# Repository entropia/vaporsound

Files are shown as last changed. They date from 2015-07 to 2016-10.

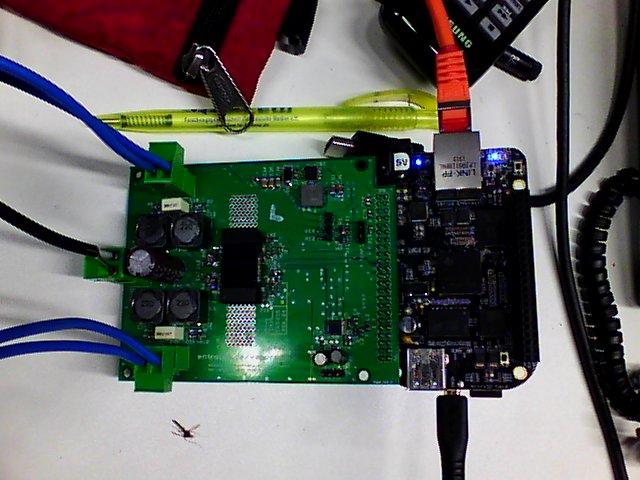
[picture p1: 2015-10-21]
docs/flir/front1.jpg

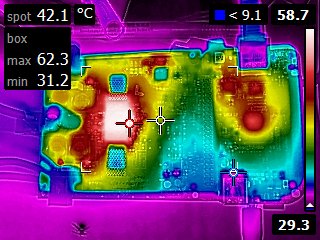
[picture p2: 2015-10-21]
docs/flir/front1_ir.jpg

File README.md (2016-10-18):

# vaporsound

Our custom audio amplifier for the hackerspace

## hardware

The vaporsound board can drive two speakers with up to 50W each and has an analog stereo input.
It is connected to a beaglebone black which provides an ethernet port.
The vaporsound board needs a 24V power supply and provides 5V to the beaglebone black.

The hardware is designed in Eagle.

## mechanical

The vaporsound case is designed in Rhino3D and can be lasercut from 4mm wood.

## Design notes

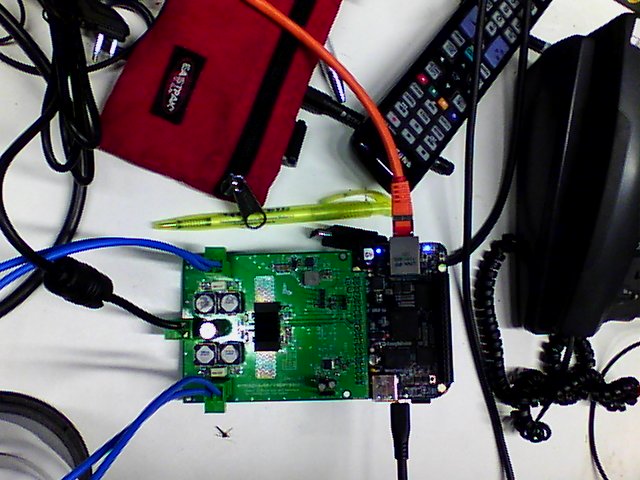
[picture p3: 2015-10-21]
docs/flir/front2.jpg

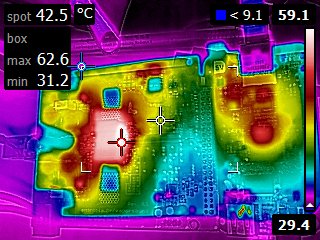
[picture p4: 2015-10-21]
docs/flir/front3_ir.jpg

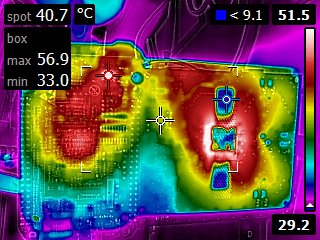
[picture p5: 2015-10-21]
docs/flir/back2_ir.jpg

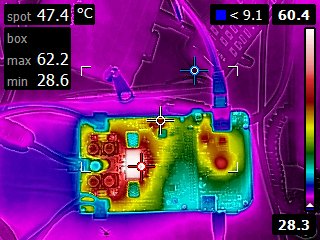
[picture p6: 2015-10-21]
docs/flir/front2_ir.jpg

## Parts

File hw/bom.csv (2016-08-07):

 | Part | Value | Device | Package | Description | MF | MPN | OC_FARNELL | OC_NEWARK | PROD_ID
X | R1 | 0R | R-EU_R0603 | R0603 | RESISTOR, European symbol
X | R2 | 0R | R-EU_R0603 | R0603 | RESISTOR, European symbol
X | R16 | 0R | R-EU_R0603 | R0603 | RESISTOR, European symbol
X | C41 | 1000u | CPOL-EUE5-10.5 | E5-10,5 | POLARIZED CAPACITOR, European symbol
vorhanden | C1 | 100n | C-EUC0603 | C0603 | CAPACITOR, European symbol
vorhanden | C3 | 100n | C-EUC0603 | C0603 | CAPACITOR, European symbol
vorhanden | C5 | 100n | C-EUC0603 | C0603 | CAPACITOR, European symbol
vorhanden | C11 | 100n | C-EUC0603 | C0603 | CAPACITOR, European symbol
vorhanden | C12 | 100n | C-EUC0603 | C0603 | CAPACITOR, European symbol
vorhanden | C13 | 100n | C-EUC0603 | C0603 | CAPACITOR, European symbol
vorhanden | C18 | 100n | C-EUC0603 | C0603 | CAPACITOR, European symbol
vorhanden | C19 | 100n | C-EUC0603 | C0603 | CAPACITOR, European symbol
vorhanden | C20 | 100n | C-EUC0603 | C0603 | CAPACITOR, European symbol
vorhanden | C21 | 100n | C-EUC0603 | C0603 | CAPACITOR, European symbol
vorhanden | C22 | 100n | C-EUC0603 | C0603 | CAPACITOR, European symbol
vorhanden | C23 | 100n | C-EUC0603 | C0603 | CAPACITOR, European symbol
vorhanden | C24 | 100n | C-EUC0603 | C0603 | CAPACITOR, European symbol
vorhanden | C25 | 100n | C-EUC0603 | C0603 | CAPACITOR, European symbol
vorhanden | C39 | 100n | C-EUC0603 | C0603 | CAPACITOR, European symbol
vorhanden | C40 | 100n | C-EUC0603 | C0603 | CAPACITOR, European symbol
vorhanden | C42 | 100n | C-EUC0603 | C0603 | CAPACITOR, European symbol
vorhanden | C43 | 100n | C-EUC0603 | C0603 | CAPACITOR, European symbol
vorhanden | R15 | 10k | R-EU_R0603 | R0603 | RESISTOR, European symbol
vorhanden | R1 | 10k | R-EU_R0805 | R0805 | RESISTOR, European symbol
vorhanden | R2 | 10k | R-EU_R0805 | R0805 | RESISTOR, European symbol
vorhanden | R3 | 10k | R-EU_R0805 | R0805 | RESISTOR, European symbol
vorhanden | R4 | 10k | R-EU_R0805 | R0805 | RESISTOR, European symbol
vorhanden | R5 | 10k | R-EU_R0805 | R0805 | RESISTOR, European symbol
X | C30 | 10n | C-EUC0603 | C0603 | CAPACITOR, European symbol
X | C2 | 10u | C-EUC0805 | C0805 | CAPACITOR, European symbol
X | C4 | 10u | C-EUC0805 | C0805 | CAPACITOR, European symbol
X | C6 | 10u | C-EUC0805 | C0805 | CAPACITOR, European symbol
X | C34 | 10u | C-EUC1206 | C1206 | CAPACITOR, European symbol
X | C35 | 10u | C-EUC1206 | C1206 | CAPACITOR, European symbol
X | C36 | 10u | C-EUC1206 | C1206 | CAPACITOR, European symbol
X | C44 | 1n | C-EUC0603 | C0603 | CAPACITOR, European symbol
X | C7 | 1u | CPOL-EUE2-5 | E2-5 | POLARIZED CAPACITOR, European symbol
X | C8 | 1u | CPOL-EUE2-5 | E2-5 | POLARIZED CAPACITOR, European symbol
X | C33 | 1u | C-EUC0805 | C0805 | CAPACITOR, European symbol
X | C37 | 1u | C-EUC1206 | C1206 | CAPACITOR, European symbol
X | C38 | 1u | C-EUC1206 | C1206 | CAPACITOR, European symbol
X | L2 | 1uH | R-EU_R0805 | R0805 | RESISTOR, European symbol
X | L7 | 1uH | R-EU_R0805 | R0805 | RESISTOR, European symbol
X | R5 | 20R | R-EU_R1206 | R1206 | RESISTOR, European symbol
X | R6 | 20R | R-EU_R1206 | R1206 | RESISTOR, European symbol
X | C45 | 22u | C-EUC1206 | C1206 | CAPACITOR, European symbol
X | L1 | 22u | L-EUSRR1210 | SRR1210 | INDUCTOR, European symbol
X | L3 | 22u | L-EUSRR1210 | SRR1210 | INDUCTOR, European symbol
X | L4 | 22u | L-EUSRR1210 | SRR1210 | INDUCTOR, European symbol
X | L5 | 22u | L-EUSRR1210 | SRR1210 | INDUCTOR, European symbol
X | L6 | 22u | L-EUIHLP-3232DZ-11 | IHLP-3232DZ-11 | INDUCTOR, European symbol
X | R4 | 2k2 | R-EU_R0603 | R0603 | RESISTOR, European symbol
X | R3 | 2R2 | R-EU_R0603 | R0603 | RESISTOR, European symbol
X | C16 | 330p | C-EUC0603 | C0603 | CAPACITOR, European symbol
X | C17 | 330p | C-EUC0603 | C0603 | CAPACITOR, European symbol
X | R6 | 330R | R-EU_R0805 | R0805 | RESISTOR, European symbol
X | C26 | 470n | C-EU050-045X075 | C050-045X075 | CAPACITOR, European symbol
X | C27 | 470n | C-EU050-045X075 | C050-045X075 | CAPACITOR, European symbol
X | C31 | 47u | C-EUC1206 | C1206 | CAPACITOR, European symbol
X | C32 | 47u | C-EUC1206 | C1206 | CAPACITOR, European symbol
X | R11 | 4k7 | R-EU_R0603 | R0603 | RESISTOR, European symbol
X | R12 | 4k7 | R-EU_R0603 | R0603 | RESISTOR, European symbol
X | R13 | 4k7 | R-EU_R0603 | R0603 | RESISTOR, European symbol
X | R14 | 4k7 | R-EU_R0603 | R0603 | RESISTOR, European symbol
X | R19 | 4k7 | R-EU_R0603 | R0603 | RESISTOR, European symbol
X | C14 | 4n7 | C-EUC0603 | C0603 | CAPACITOR, European symbol
X | C28 | 4u7 | C-EUC0805 | C0805 | CAPACITOR, European symbol
X | C29 | 4u7 | C-EUC0805 | C0805 | CAPACITOR, European symbol
X | C15 | 680p | C-EUC0603 | C0603 | CAPACITOR, European symbol
X | R7 | 6R2 | R-EU_R1206 | R1206 | RESISTOR, European symbol
X | R8 | 6R2 | R-EU_R1206 | R1206 | RESISTOR, European symbol
X | R9 | 6R2 | R-EU_R1206 | R1206 | RESISTOR, European symbol
X | R10 | 6R2 | R-EU_R1206 | R1206 | RESISTOR, European symbol
X | D1 | B340A-13-F | DIODESMA | SMADIODE | Diode
X | T1 | BC847C | BC847A-NPN-SOT23-BEC | SOT23-BEC | NPN Transistror
X | Q1 | BSS138 | MOSFET-NCHANNELBSS138 | SOT23-3 | Common NMOSFET Parts |  |  |  |  | TRANS-00830
X | Q2 | BSS138 | MOSFET-NCHANNELBSS138 | SOT23-3 | Common NMOSFET Parts |  |  |  |  | TRANS-00830
 | C9 | DNP | C-EUC0603 | C0603 | CAPACITOR, European symbol
 | C10 | DNP | C-EUC0603 | C0603 | CAPACITOR, European symbol
 | R17 | DNP | R-EU_R0603 | R0603 | RESISTOR, European symbol
 | R18 | DNP | R-EU_R0603 | R0603 | RESISTOR, European symbol
X | SW1 | EC12E_SW | EC12E_SW | ALPS_EC12E_SW | ALPS rotary Encoder EC12E series with switch |  | EC12E2424407 | 1520813 | 74M1068
X | U$2 | LM22676 | LM2267_123 | DDA0008B | LM2267x
X | P9 | MA23-2 | MA23-2 | MA23-2
X | P8 | MA23-2 | MA23-2 | MA23-2
X | PWR | MSTBV2 | MSTBV2 | MSTBV2 | PHOENIX |  | MSTBV 2,5/2-GF-5.08 | 1792792 | 69R9845
X | SPKR1 | MSTBV2 | MSTBV2 | MSTBV2 | PHOENIX |  | MSTBV 2,5/2-GF-5.08 | 1792792 | 69R9845
X | SPKR2 | MSTBV2 | MSTBV2 | MSTBV2 | PHOENIX |  | MSTBV 2,5/2-GF-5.08 | 1792792 | 69R9845
X | U$3 | PCM1808 | PCM1808 | TSSOP14
X | U$1 | STA350BW | STA350BW | POWERSSO-36
X | DISP |  | MA04-1 | MA04-1 | PIN HEADER |  |  | unknown | unknown
X | IN |  | MA03-1 | MA03-1 | PIN HEADER |  |  | unknown | unknown
X | TEMP |  | MA03-1 | MA03-1 | PIN HEADER |  |  | unknown | unknown
X | ENCODER |  | PINHD-1X4/90 | 1X04/90 | PIN HEADER
X | PWN_BTN_LED |  | PINHD-1X4/90 | 1X04/90 | PIN HEADER
X | PWR_CON |  | PINHD-1X2/90 | 1X02/90 | PIN HEADER
X | JP1 |  | PINHD-1X4/90 | 1X04/90 | PIN HEADER
X | LED1 |  | LED3MM | LED3MM | LED
X | S1 |  | 40-XX | B3F-40XX | OMRON SWITCH | OMRON COMPONENTS USA | B3F-4000 | 176434 | 36K3105
X | JP1 |  | PINHD-1X4/90 | 1X04/90 | PIN HEADER

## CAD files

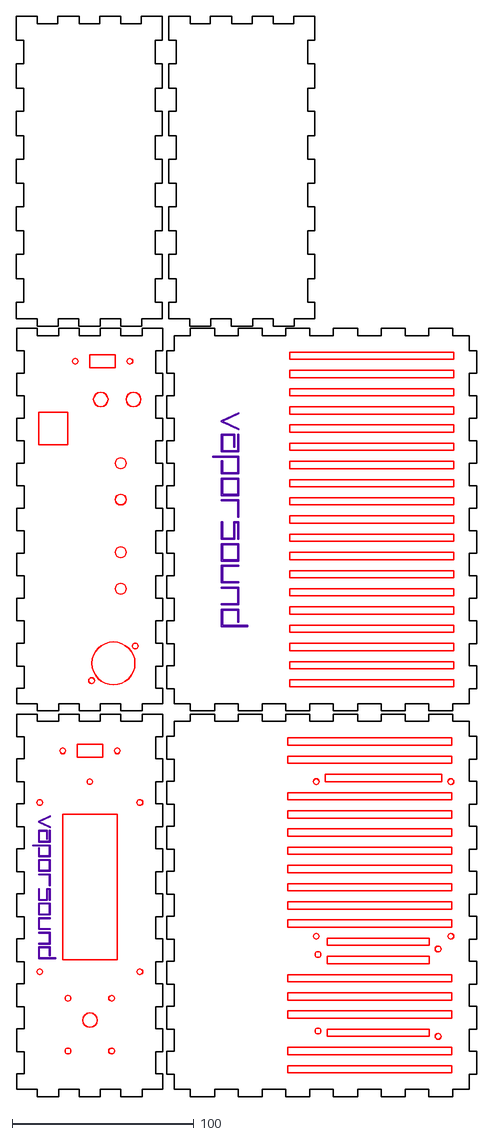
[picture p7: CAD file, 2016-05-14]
mechanical/vaporsound_case.dxf
252.8 x 593.6

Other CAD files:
mechanical/vaporsound_case.3dm

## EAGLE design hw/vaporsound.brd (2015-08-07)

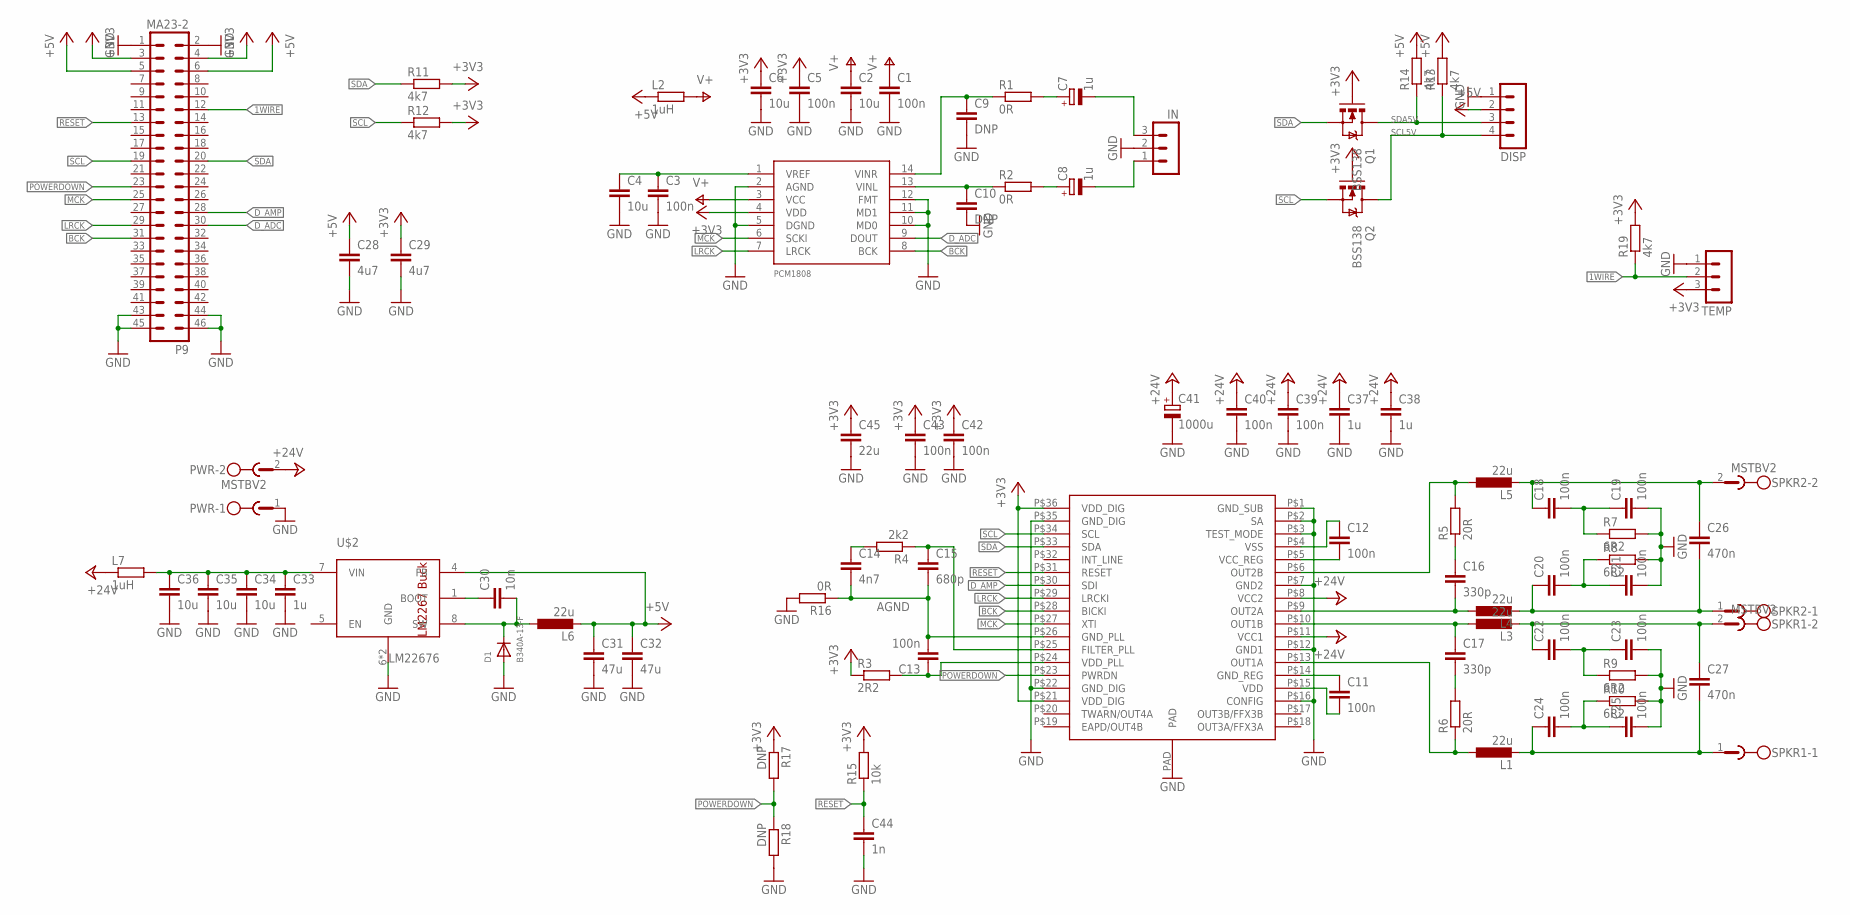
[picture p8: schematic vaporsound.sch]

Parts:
C1, C3, C5, C11, C12, C13, C18, C19, C20, C21, C22, C23, C24, C25, C39, C40, C42, C43: 100n; C0603
C2, C4, C6: 10u; C0805
C7, C8: 1u; E2-5
C9, C10: DNP; C0603
C14: 4n7; C0603
C15: 680p; C0603
C16, C17: 330p; C0603
C26, C27: 470n; C050-045X075
C28, C29: 4u7; C0805
C30: 10n; C0603
C31, C32: 47u; C1206
C33: 1u; C0805
C34, C35, C36: 10u; C1206
C37, C38: 1u; C1206
C41: 1000u; E5-10,5
C44: 1n; C0603
C45: 22u; C1206
D1: B340A-13-F; SMADIODE
DISP: MA04-1
IN: MA03-1
L1, L3, L4, L5: 22u; SRR1210
L2, L7: 1uH; R0805
L6: 22u; IHLP-3232DZ-11
P9: MA23-2
PWR: MSTBV2
Q1, Q2: BSS138; SOT23-3
R1, R2, R16: 0R; R0603
R3: 2R2; R0603
R4: 2k2; R0603
R5, R6: 20R; R1206
R7, R8, R9, R10: 6R2; R1206
R11, R12, R13, R14, R19: 4k7; R0603
R15: 10k; R0603
R17, R18: DNP; R0603
SPKR1, SPKR2: MSTBV2
TEMP: MA03-1
U$1: STA350BW; POWERSSO-36
U$2: LM22676; DDA0008B
U$3: PCM1808; TSSOP14

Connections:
1WIRE: P9.12, R19.1, TEMP.2
24V_DIGITAL: C33.1, C34.1, C35.1, C36.1, L7.2, U$2.7 (VIN)
+3V3: C5.1, C6.1, C29.1, C42.1, C43.1, C45.1, P9.3, P9.4, Q1.1 (G), Q2.1 (G), R3.1, R11.2, R12.2, R15.2, R17.1, R19.2, TEMP.3, U$1.P$21 (VDD_DIG), U$1.P$36 (VDD_DIG), U$3.4 (VDD)
+5V: C28.1, C31.1, C32.1, DISP.2, L2.1, L6.P$2 (2), P9.5, P9.6, R13.2, R14.2, U$2.4 (FB)
+24V: C37.1, C38.1, C39.1, C40.1, C41.+, L7.1, PWR.2, U$1.P$8 (VCC2), U$1.P$11 (VCC1)
ADC_VREF: C3.1, C4.1, U$3.1 (VREF)
AGND: C13.2, C14.2, C15.2, R16.1, U$1.P$26 (GND_PLL)
BCK: P9.31, U$1.P$28 (BICKI), U$3.8 (BCK)
BOOST: C30.1, U$2.1 (BOOT)
C_LEFT: C8.+, R2.2
C_RIGHT: C7.+, R1.2
D_ADC: P9.30, U$3.9 (DOUT)
D_AMP: P9.28, U$1.P$30 (SDI)
FILTER_PLL: C15.1, R4.1, U$1.P$25 (FILTER_PLL)
GND: C1.2, C2.2, C3.2, C4.2, C5.2, C6.2, C9.2, C10.2, C19.2, C21.2, C23.2, C25.2, C28.2, C29.2, C31.2, C32.2, C33.2, C34.2, C35.2, C36.2, C37.2, C38.2, C39.2, C40.2, C41.-, C42.2, C43.2, C44.2, C45.2, D1.A, DISP.1, IN.2, P9.1, P9.2, P9.43, P9.44, P9.45, P9.46, PWR.1, R7.2, R8.2, R9.2, R10.2, R16.2, R18.2, TEMP.1, U$1.P$1 (GND_SUB), U$1.P$2 (SA), U$1.P$3 (TEST_MODE), U$1.P$7 (GND2), U$1.P$12 (GND1), U$1.P$16 (CONFIG), U$1.P$22 (GND_DIG), U$1.P$35 (GND_DIG), U$1.PAD, U$2.6 (GND), U$2.EPAD (GND), U$3.2 (AGND), U$3.5 (DGND), U$3.10 (MD0), U$3.11 (MD1), U$3.12 (FMT)
GND_REG: C11.1, U$1.P$14 (GND_REG)
LEFT_INPUT: C8.-, IN.1
LRCK: P9.29, U$1.P$29 (LRCKI), U$3.7 (LRCK)
MCK: P9.25, U$1.P$27 (XTI), U$3.6 (SCKI)
unnamed: C17.2, R6.2
unnamed: C14.1, R4.2
unnamed: C16.1, R5.1
unnamed: C18.2, C19.1, R7.1
unnamed: C20.2, C21.1, R8.1
unnamed: C24.2, C25.1, R10.1
unnamed: C22.2, C23.1, R9.1
OUT1A: L1.P$1 (1), R6.1, U$1.P$13 (OUT1A)
OUT1B: C17.1, L3.P$1 (1), U$1.P$10 (OUT1B)
OUT2A: C16.2, L4.P$1 (1), U$1.P$9 (OUT2A)
OUT2B: L5.P$1 (1), R5.2, U$1.P$6 (OUT2B)
POWERDOWN: P9.23, R17.2, R18.1, U$1.P$23 (PWRDN)
RESET: C44.1, P9.13, R15.1, U$1.P$31 (RESET)
RIGHT_INPUT: C7.-, IN.3
SCL: P9.19, Q2.2 (S), R12.1, U$1.P$34 (SCL)
SCL5V: DISP.4, Q2.3 (D), R13.1
SDA: P9.20, Q1.2 (S), R11.1, U$1.P$33 (SDA)
SDA5V: DISP.3, Q1.3 (D), R14.1
SPKR1A: C24.1, C27.2, L1.P$2 (2), SPKR1.1
SPKR1B: C22.1, C27.1, L3.P$2 (2), SPKR1.2
SPKR2A: C20.1, C26.2, L4.P$2 (2), SPKR2.1
SPKR2B: C18.1, C26.1, L5.P$2 (2), SPKR2.2
SW: C30.2, D1.C, L6.P$1 (1), U$2.8 (SW)
V+: C1.1, C2.1, L2.2, U$3.3 (VCC)
VCC_REG: C12.2, U$1.P$5 (VCC_REG)
VDD: C11.2, U$1.P$15 (VDD)
VDD_PLL: C13.1, R3.2, U$1.P$24 (VDD_PLL)
VIN_L: C10.1, R2.1, U$3.13 (VINL)
VIN_R: C9.1, R1.1, U$3.14 (VINR)
VSS: C12.1, U$1.P$4 (VSS)

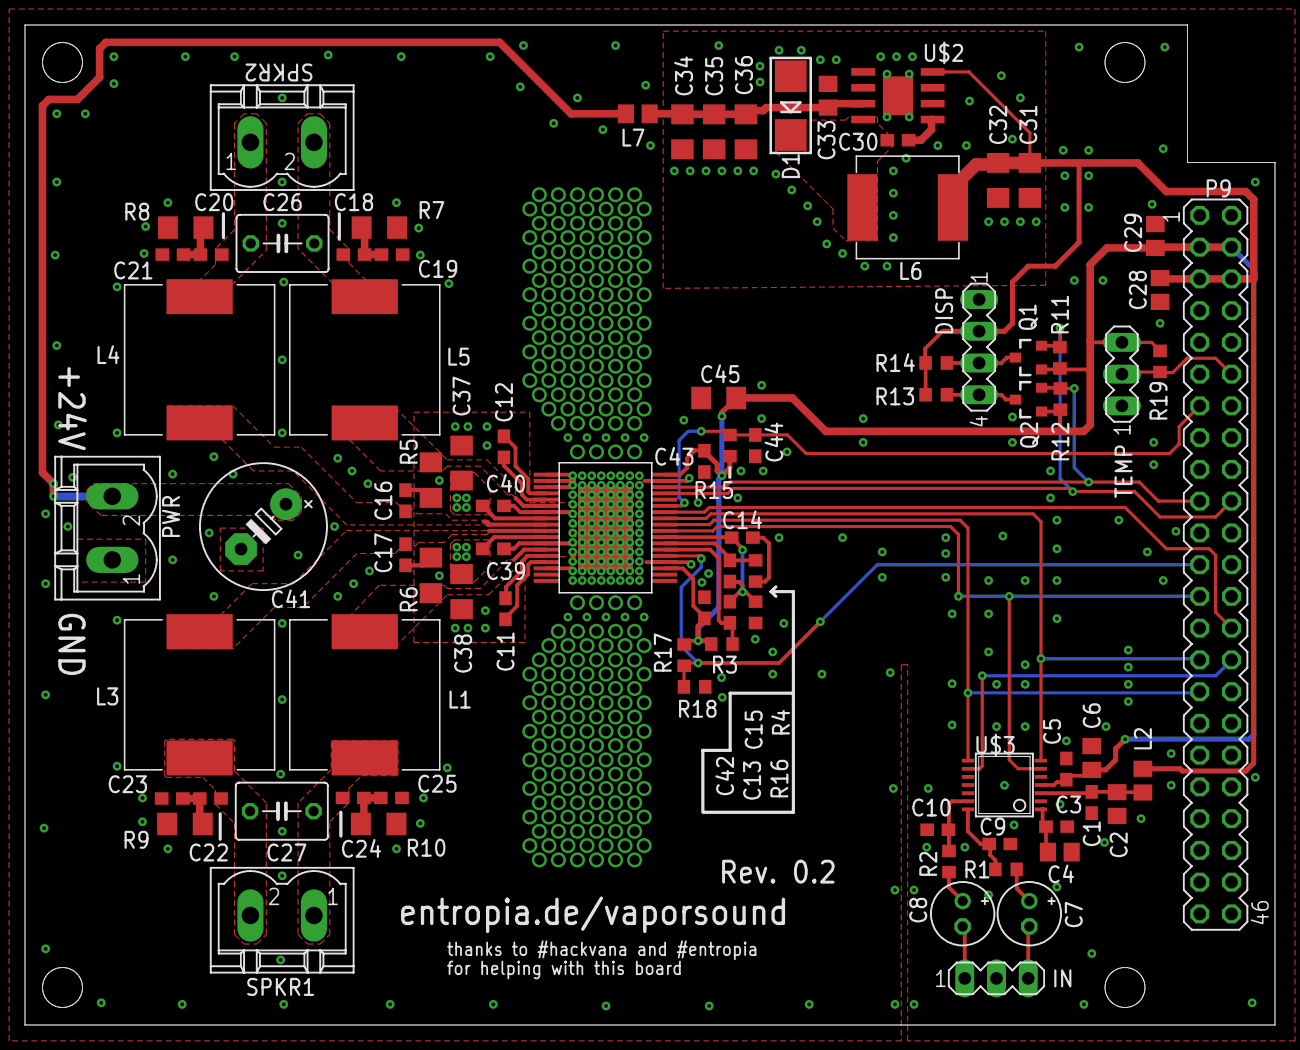
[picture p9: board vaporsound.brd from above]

Board: 2 copper layers, 100.0 x 80.0 mm, 84 parts (0 on the bottom side), 49 nets.

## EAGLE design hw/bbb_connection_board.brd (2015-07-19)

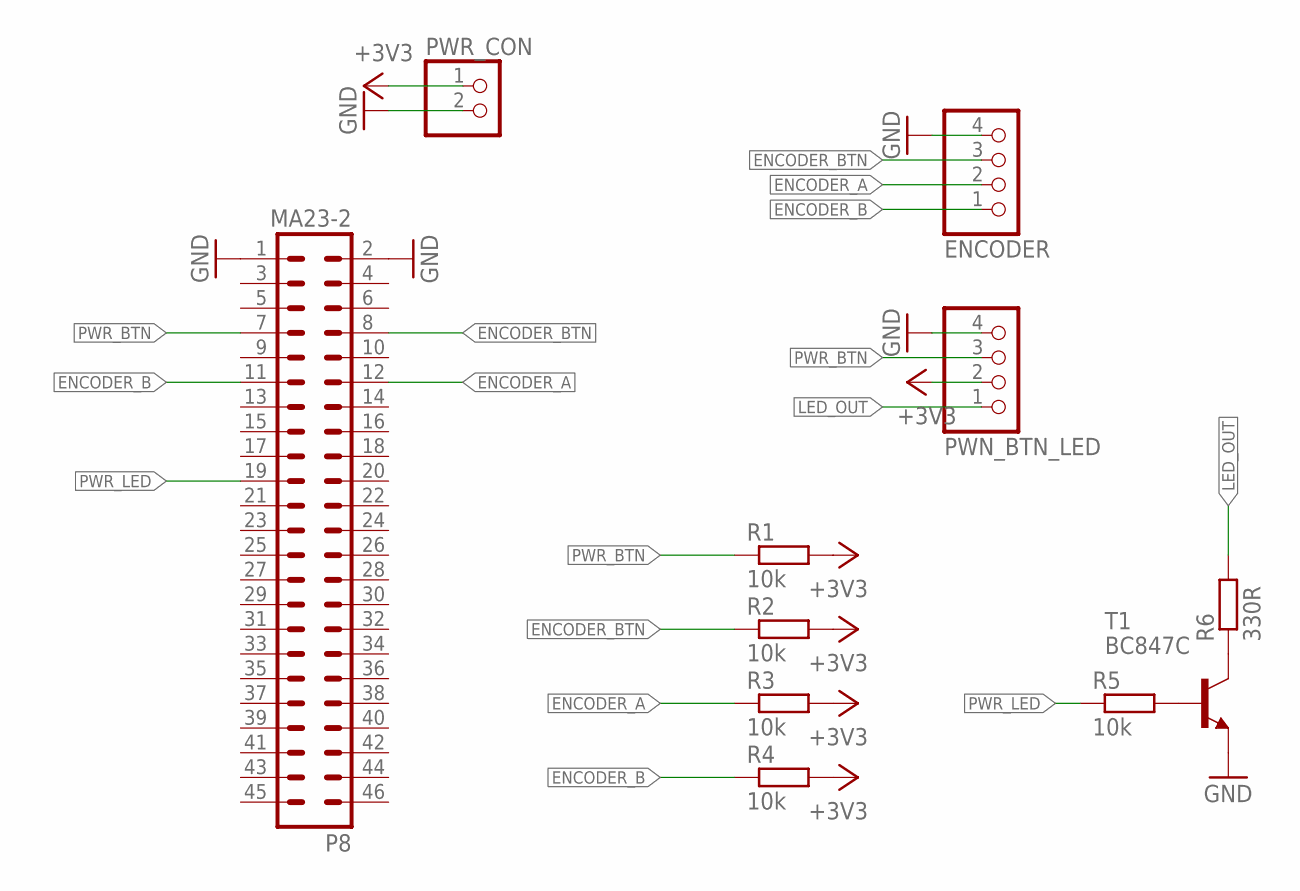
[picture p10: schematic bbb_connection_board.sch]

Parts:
ENCODER: PINHD-1X4/90; 1X04/90
P8: MA23-2
PWN_BTN_LED: PINHD-1X4/90; 1X04/90
PWR_CON: PINHD-1X2/90; 1X02/90
R1, R2, R3, R4, R5: 10k; R0805
R6: 330R; R0805
T1: BC847C; SOT23-BEC

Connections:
+3V3: PWN_BTN_LED.2, PWR_CON.1, R1.2, R2.2, R3.2, R4.2
ENCODER_A: ENCODER.2, P8.12, R3.1
ENCODER_B: ENCODER.1, P8.11, R4.1
ENCODER_BTN: ENCODER.3, P8.8, R2.1
GND: ENCODER.4, P8.1, P8.2, PWN_BTN_LED.4, PWR_CON.2, T1.E
LED_OUT: PWN_BTN_LED.1, R6.2
unnamed: R5.2, T1.B
unnamed: R6.1, T1.C
PWR_BTN: P8.7, PWN_BTN_LED.3, R1.1
PWR_LED: P8.19, R5.1

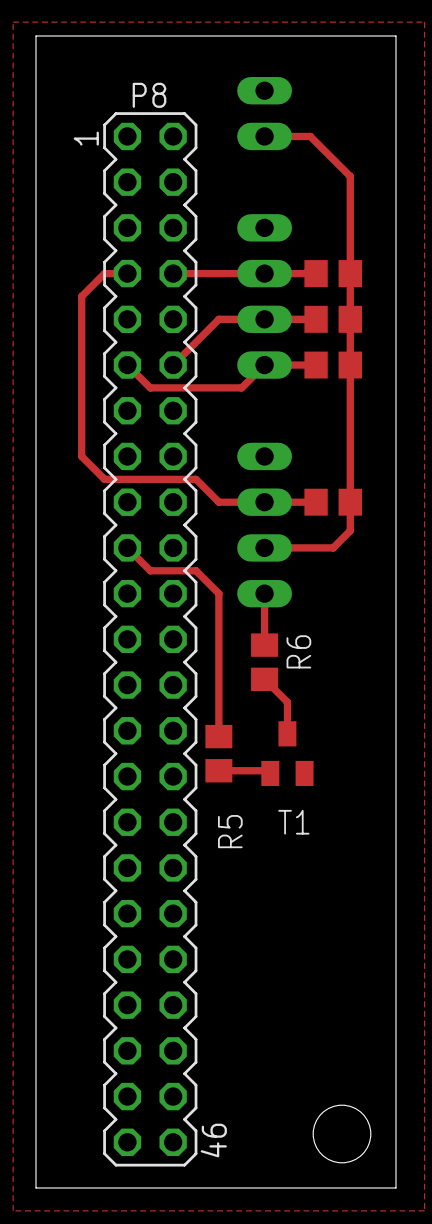
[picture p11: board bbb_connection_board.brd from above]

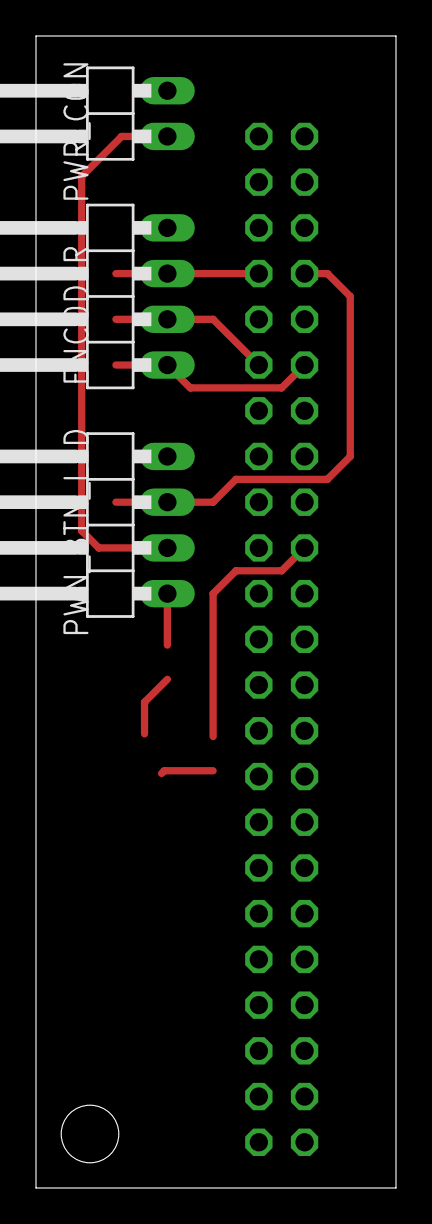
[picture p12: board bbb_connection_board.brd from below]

Board: 2 copper layers, 20.0 x 64.0 mm, 11 parts (3 on the bottom side), 10 nets.

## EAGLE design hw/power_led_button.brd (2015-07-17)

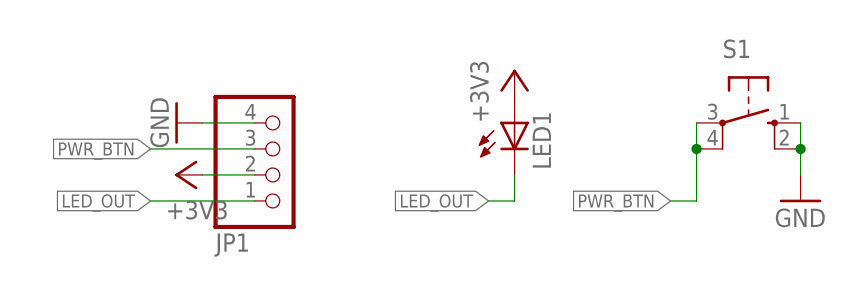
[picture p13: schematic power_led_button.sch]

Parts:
JP1: PINHD-1X4/90; 1X04/90
LED1: LED3MM
S1: 40-XX; B3F-40XX

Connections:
+3V3: JP1.2, LED1.A
GND: JP1.4, S1.1 (S), S1.2 (S1)
LED_OUT: JP1.1, LED1.K (C)
PWR_BTN: JP1.3, S1.3, S1.4 (P1)

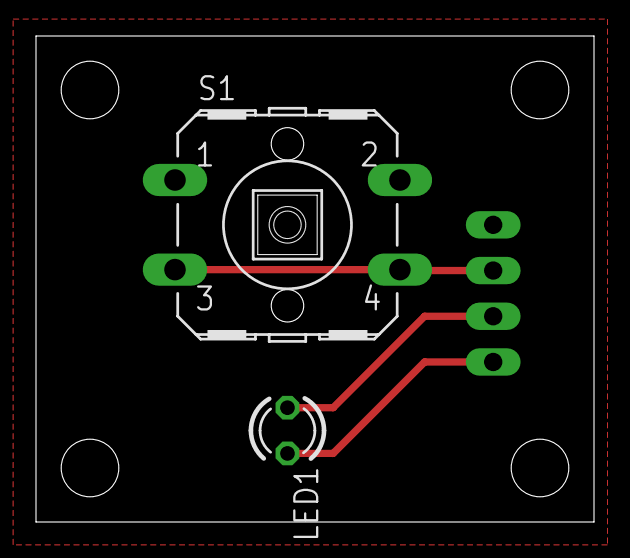
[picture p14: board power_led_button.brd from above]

Board: 2 copper layers, 31.0 x 27.0 mm, 3 parts (1 on the bottom side), 4 nets.

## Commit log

2015-06-24 initial schematic draft
    [vaporsound.brd, vaporsound.sch]
2015-06-29 schematics done-ish
    [vaporsound.brd, vaporsound.sch]
2015-07-06 layout voltage regulator and add some capacitors
    [vaporsound.brd, vaporsound.sch]
2015-07-06 add gerbers of eval board
    [NCDrill.drl]
2015-07-06 modify footprint so it can be produced without additional fee
    minimal distance between traces should be 6mil
2015-07-06 begin layout of 24v side of sta350
    [vaporsound.brd, vaporsound.sch]
2015-07-06 output stage almost routed
    [vaporsound.brd, vaporsound.sch]
2015-07-07 begin component placement at input side of sta350
    [vaporsound.brd, vaporsound.sch]
2015-07-09 add thermal vias for sta350
    [vaporsound.brd, vaporsound.sch]
2015-07-09 use 0603 capacitors instead of 0402 ones
    0603 is small enough for the board
    [vaporsound.brd, vaporsound.sch]
2015-07-10 do some more floorplanning
    [vaporsound.brd]
2015-07-10 output stage fully routed, adc routed
    [vaporsound.brd, vaporsound.sch]
2015-07-12 board fully routed
    [vaporsound.brd]
2015-07-12 fix wrong angles
    [vaporsound.brd]
2015-07-12 Add pullup and pulldown STA350BW + minor layout fixes
    [vaporsound.brd, vaporsound.sch]
2015-07-12 Reroute I2S connections
    [vaporsound.brd]
2015-07-12 ground plane stitching + thermal vias
    [vaporsound.brd, vaporsound.sch]
2015-07-13 some more silkscreen fixes
    [vaporsound.brd]
2015-07-13 changes for easier manufacturability
    minimum trace width 8mil
    minimum clearance 7mil (8mil except the sta350bw)
    [vaporsound.brd, vaporsound.sch]
2015-07-13 add more thermal vias
    [vaporsound.brd]
2015-07-13 slightly move the sta350 to the lower end of the pcb
    [vaporsound.brd]
2015-07-13 add inductor name to silkscreen
    [vaporsound.brd, vaporsound.sch]
2015-07-13 move reset to different bbb pin and remove pull-down resistor
    reset of the sta350 is now connected to a pin with pull-up on the bbb instead of one with a pull-down
    [vaporsound.brd, vaporsound.sch]
2015-07-13 remove soldermask and move some passives to be able to solder a heatsink to the board
    [vaporsound.brd]
2015-07-14 add 1wire temperature sensor + some thermal optimizations
    [vaporsound.brd, vaporsound.sch]
2015-07-14 add some greetings on the silkscreen
    [vaporsound.brd]
2015-07-14 move resistors a bit away from the heatsink
    [vaporsound.brd]
2015-07-15 begin second board plugged onto the bbb
    pin mapping definitions
    [bbb_connection_board.brd, bbb_connection_board.sch]
2015-07-16 schematic of bbb connection board
    [bbb_connection_board.brd, bbb_connection_board.sch]
2015-07-17 bbb connection board routed
    [bbb_connection_board.brd, bbb_connection_board.sch]
2015-07-17 add encoder board
    [rotary_encoder_board.brd, rotary_encoder_board.sch]
2015-07-17 move connectors to bottom layer
    the connector to the bbb also needs to be mounted on the bottom side, but can't be simply mirrored, since that would change the pinout
    [bbb_connection_board.brd]
2015-07-17 use angled pinheaders
    [bbb_connection_board.brd, bbb_connection_board.sch, rotary_encoder_board.brd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]
2015-07-17 add power button and power led board
    [power_led_button.brd, power_led_button.sch]
2015-07-19 add missing values
    [bbb_connection_board.brd, bbb_connection_board.sch, vaporsound.brd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]
2015-07-25 route last unrouted trace and increase version number
    [vaporsound.brd]
2015-08-07 minor groundplane fix
    [vaporsound.brd]
2016-05-14 add case design for laser cutting
    use 4mm wood for the case
    [vaporsound_case.3dm, vaporsound_case.dxf]
2016-06-18 use current uboot
2016-06-18 call mount_ram_overlay in inittab
2016-06-18 ram-overlay: only /dev mount exists at early boot
2016-06-18 add initialization framework
2016-06-18 move init script
    /sys needs to be mounted to detect the mac address
2016-06-18 configure rotary encoder and pwm
2016-08-06 create merged BOM of all boards
    [bom.csv]
2016-10-18 add information about the hardware and case to README.md

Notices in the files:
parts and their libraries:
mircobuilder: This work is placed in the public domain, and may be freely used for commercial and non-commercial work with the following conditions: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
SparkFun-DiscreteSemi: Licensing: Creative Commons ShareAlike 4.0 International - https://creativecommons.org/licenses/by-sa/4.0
